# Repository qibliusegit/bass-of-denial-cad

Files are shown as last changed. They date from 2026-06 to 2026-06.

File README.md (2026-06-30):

# bass-of-denial-cad
These are the hardware-related files for the bass I'm creating for Hack Club's Stardance! As someone that loves music, I thought building a bass would be really cool, and since I also like anime, I wanted it to look like Ryo Yamada's Fender Precision from Bocchi the Rock. But because that was somehow still too boring to me, I decided to also make it so the bass can react to overplayed guitar songs, the main inspiration being the 'No stairway! Denied!' scene in Wayne's World, which you can watch by clicking here:

Watch the video (https://www.youtube.com/embed/UCh6guovbt0)

There's loads of songs that are so overplayed on guitar that hearing them annoys people, Stairway to Heaven and Smoke on the Water to name a few. So to stop guitarists from pestering an entire room full of people (or to make them practice the music they need to actually learn at a gig session), this bass uses a Raspberry Pi Zero 2 W along with a screen to stop them in their tracks. Ryo Yamada would be proud, I hope.

oke-yamada-ryo

This repo contains screenshots, STL files, and STEP files for the bass, which was fully CADed in Onshape. It also contains the wiring diagram, which I found on StewMac (the manufacturers of the pickups I'm ordering)'s website, as well as my bill of materials.

The software files for this will be uploaded in a seperate repo as I create them, since I'm currently in the process of coding the sound recogniztion software. I will link the repo here once it exists.


Full CAD of the bass


The green section represents where the riff recognition module would go. There's no fancy wiring or anything here, just a Raspberry Pi Zero 2 W hooked up to a small screen.

The purple section represents the wiring for the pickups and output jack for the bass. The specific wiring diagram can be seen here:



In this diagram, the pickups (which are on the left) would go into the holes in the middle of the guitar. The two potentiometers and the output jack would be placed near the bottom left edge (from the perspective shown in the CAD).

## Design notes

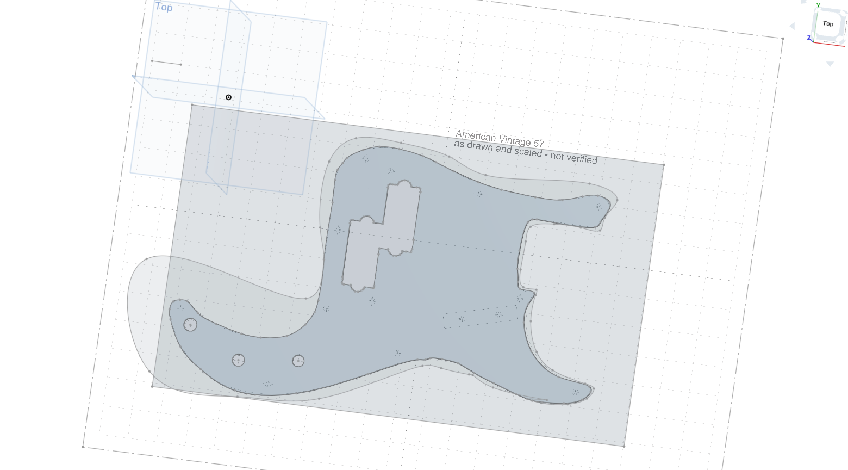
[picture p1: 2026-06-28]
bass pick guard.png

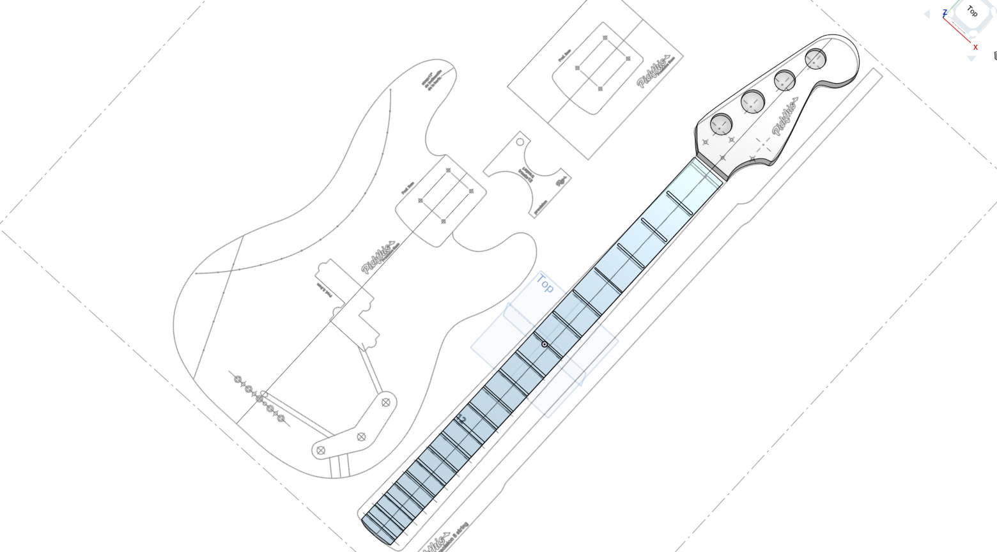
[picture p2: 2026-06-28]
bass neck and headstock.png

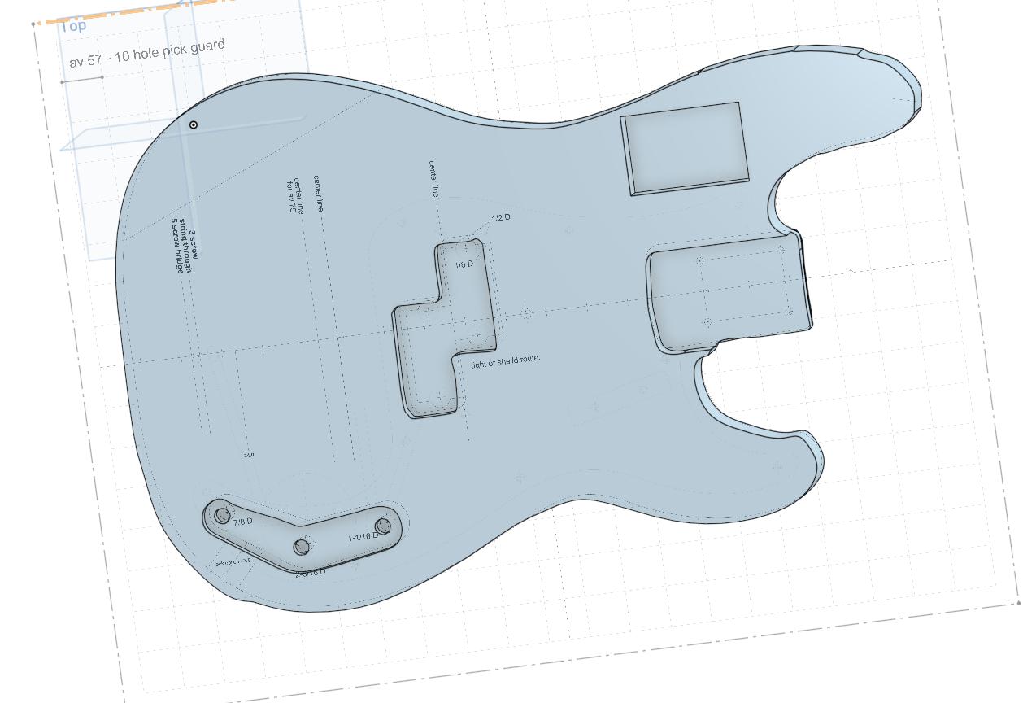
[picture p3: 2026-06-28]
bass body.png

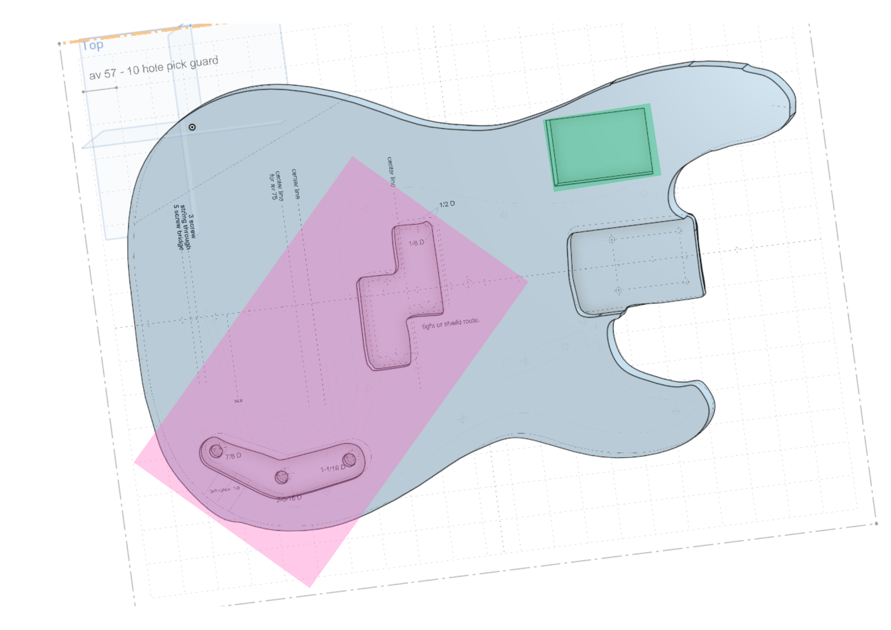
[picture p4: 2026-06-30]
bass body labelled.png

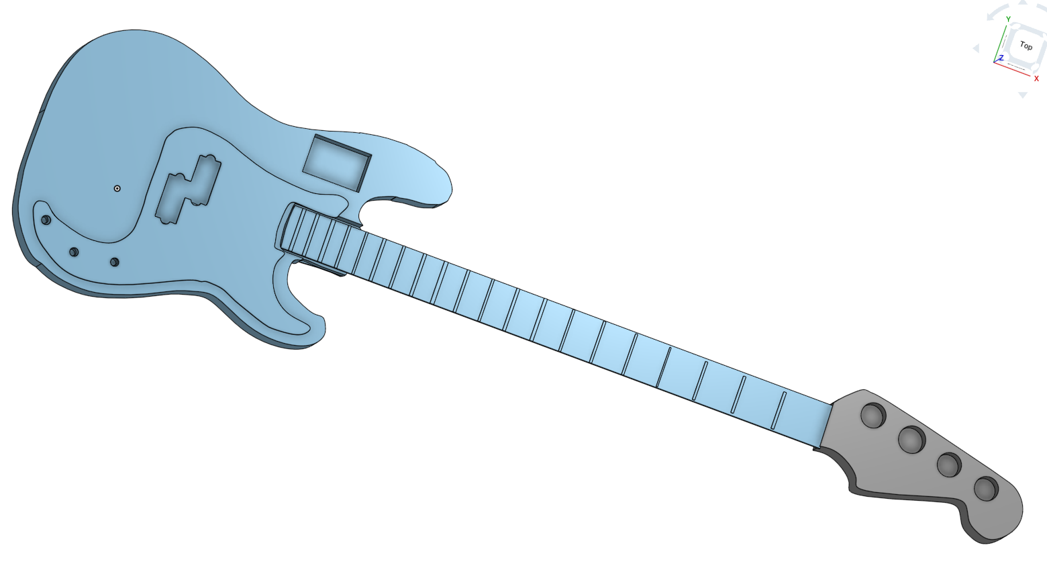
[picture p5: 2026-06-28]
bass full.png

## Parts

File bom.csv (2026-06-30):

Part Name | Part Description | Part Quantity | Total Part Price | Part Link
GOTOH VK1-19 Domed Guitar Knob for 6mm diameter pots | Knobs for volume and tone potentiometers | 2 | $9.98 | https://www.philadelphialuthiertools.com/knobs/volume-and-tone-control-knobs/gotoh-vk1-19-domed-guitar-knob-for-6mm-diameter-pots/
CTS Control Pots, Split shaft, 250K | Potentiometers for adjusting volume and tone | 2 | $16.38 | https://www.stewmac.com/electronics/components-and-parts/potentiometers/cts-control-pots/
Switchcraft 1/4" Guitar Output Jack | Jack to plug guitar into amplifier | 1 | $4.41 | https://www.philadelphialuthiertools.com/electronics/jacks/switchcraft-1-4-guitar-output-jack/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
GOTOH NBS-3 Steel Neck Plate | Plate for attaching neck to body | 1 | $9.99 | https://www.philadelphialuthiertools.com/neck-plates/gotoh-nbs-3-steel-neck-plate/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
GOTOH GB10 Bass Tuning Machines Tuners - Preconfigured Sets | Tuning machines for tuning bass strings | 1 | $46.49 | https://www.philadelphialuthiertools.com/bass-tuning-machines/gotoh-gb10-bass-tuning-machines-tuners-preconfigured-sets/
GOTOH EP-B1 Standard Size Strap Button | Buttons to attach bass strap to bass | 2 | $6.48 | https://www.philadelphialuthiertools.com/misc-hardware/gotoh-ep-b1-standard-size-strap-button/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
PIO "Blue Jacket" Capacitors for guitar .047mfd | Filters frequencies so guitar sounds right | 1 | $6.41 | https://www.philadelphialuthiertools.com/electronics/pio-blue-jacket-capacitors-for-guitar-047mfd/
StewMac Pickups for P-Bass | Senses vibration and works with amp to convert it into sound | 1 | $67.49 | https://www.stewmac.com/electronics/pickups/shop-all-our-pickups/stewmac-pickups-for-p-bass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
Hot Rod Low-profile 2-Way Truss Rod, 24" | Stabilizes neck of bass | 1 | $11.29 | https://www.stewmac.com/luthier-tools-and-supplies/materials/truss-rods/adjustable-truss-rods/hot-rod-low-profile-2-way-truss-rod/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
Jescar Stainless Steel Fretwire FW57110-S Electric Jumbo Pre-radiused, 9.5" | Shortens amount of bass string that can vibrate to make different sounds | 1 | $20.74 | https://www.philadelphialuthiertools.com/fretwire/jescar-stainless-steel-fretwire-fw57110-s-electric-jumbo-pre-radiused/
Bone Nut Pre Shaped and slotted for Fender® Precision Bass | Secures strings at correct points | 1 | $6.30 | https://www.philadelphialuthiertools.com/guitar-bass-nuts-saddles/bone-nut-pre-shaped-and-slotted-for-fender-precision-bass/
GOTOH 201B-4 4-string bass bridge | Tightens strings and holds them on body | 1 | $41.71 | https://www.philadelphialuthiertools.com/bridge-and-tailpieces/bass-bridges-and-tailpeices/gotoh-201b-4-4-string-bass-bridge/
Pickup Foam Height Springs - Precision Bass - 2 1/2" x 3/4" x 5/8" - 2 pack | Allows for adjustment of height of pickups | 1 | $2.61 | https://www.philadelphialuthiertools.com/mounting-rings/pickup-foam-height-springs-precision-bass-2-1-2-x-3-4-x-5-8-2-pack/
Raspberry Pi Zero 2 W | SBC for running program to detect sound | 1 | $17.25 | https://www.pishop.us/product/raspberry-pi-zero-2-w/?searchid=0&search_query=raspberry+pi+zero
2.8inch Capacitive Touch Display RP2350 Development Board | Screen for displaying video when specific sounds are detected | 1 | $28.95 | https://www.pishop.us/product/2-8inch-capacitive-touch-display-rp2350-development-board-240-320-ips-panel-5-point-touch-spi-accelerometer-and-gyroscope-sensor/
BNTECHGO 22 Gauge Silicone Wire red and Black | Wire for hooking up electronics | 1 | $7.48 | https://www.amazon.com/BNTECHGO-Silicone-Flexible-Strands-Stranded/dp/B01MFEV8SG?th=1
Wood | Repurposed hardwood for body, neck, and fretboard, self-sourced | 1 | $0 | N/A
Ernie Ball Regular Slinky Nickel Wound Bass Guitar Strings, 50-105 Gauge | Strings to make the bass playable | 1 | $20.42 | https://www.amazon.com/Ernie-Ball-Regular-Slinky-Nickel/dp/B000MFL7UU
Shipping + Fees from StewMac | So I can get the parts from StewMac | 1 | $22.96
Wood Glue | To make sure everything stays in one piece | 2 | $19.16 | https://www.amazon.com/Titebond-Ultimate-Wood-16-Ounces-1414/dp/B0002YQ3KA
Shipping + Fees from Philidelphia Luthier | So I can get the parts from Philidelphia Luthier | 1 | $0
 |  |  |  | Total Cost: | $366.50
 |  |  |  | (The other $10 is for leeway in cases taxes or shipping changes at all)

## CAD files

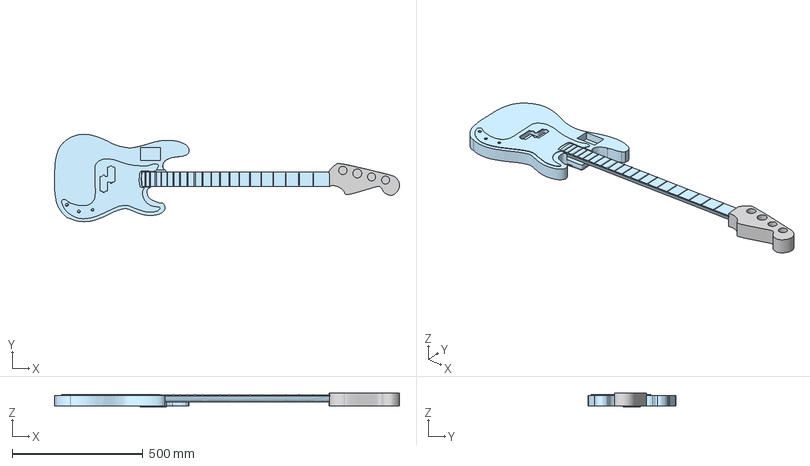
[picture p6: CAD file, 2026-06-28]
bass full.step
1317.8 x 334.3 x 54.7 mm
neck
headstock

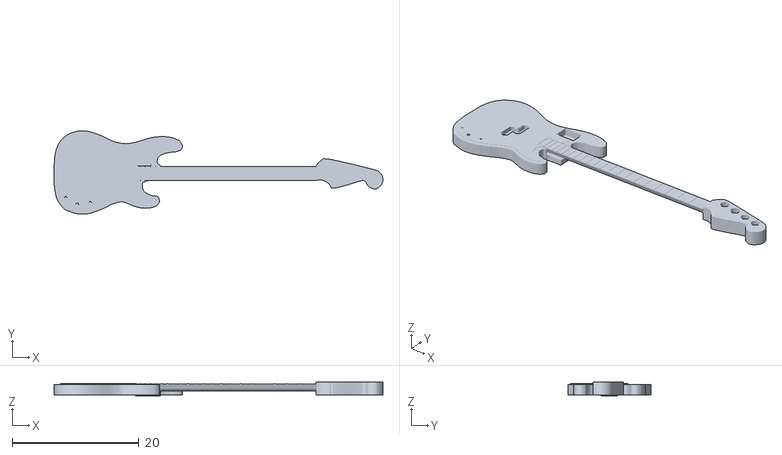
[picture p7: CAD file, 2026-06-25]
full guitar.stl
51.9 x 13.2 x 2.15

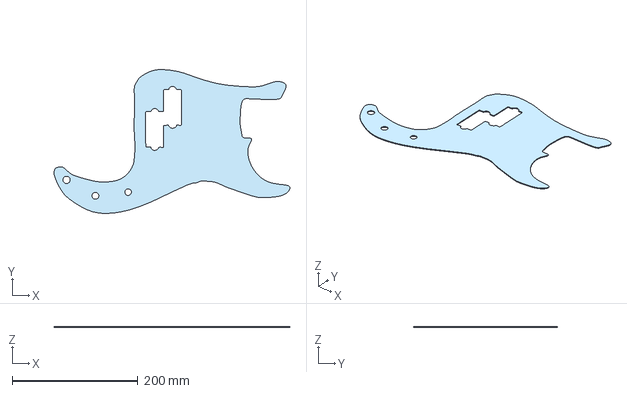
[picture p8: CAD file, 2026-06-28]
pickguard.step
375.7 x 229.0 x 1.27 mm

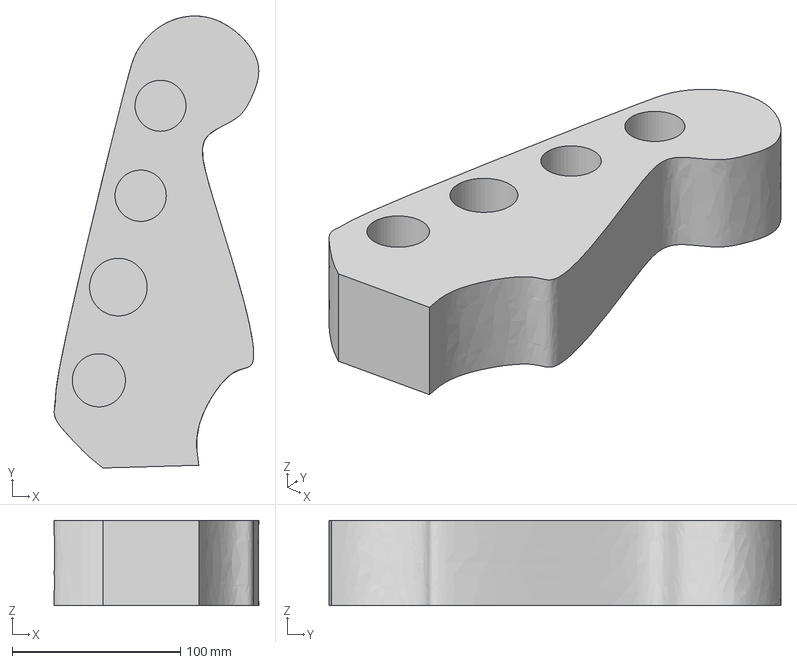
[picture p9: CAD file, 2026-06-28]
headstock.step
121.6 x 268.6 x 50.8 mm

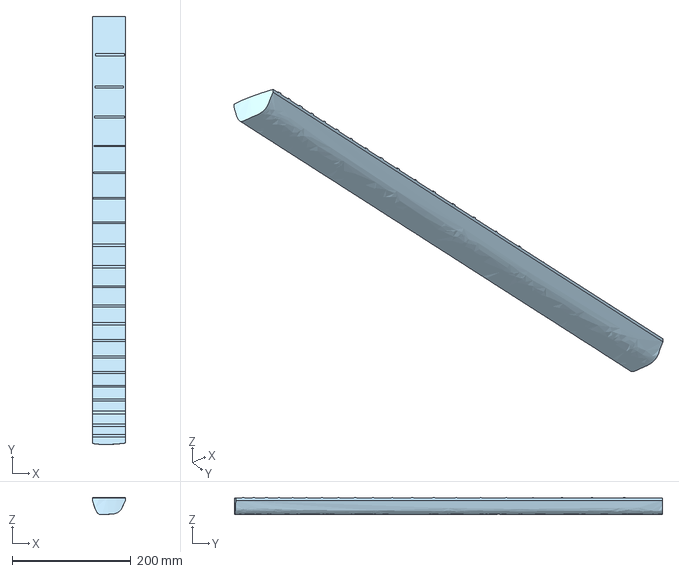
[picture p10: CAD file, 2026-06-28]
neck.step
55.8 x 720.1 x 29.2 mm

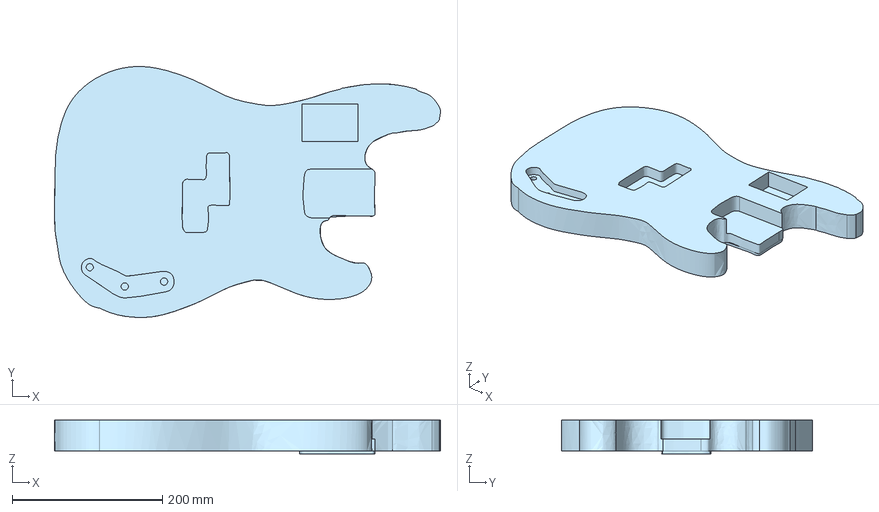
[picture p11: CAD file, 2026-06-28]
body.step
514.2 x 334.2 x 45.1 mm

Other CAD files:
body.stl
headstock.stl
neck.stl
pick guard.stl

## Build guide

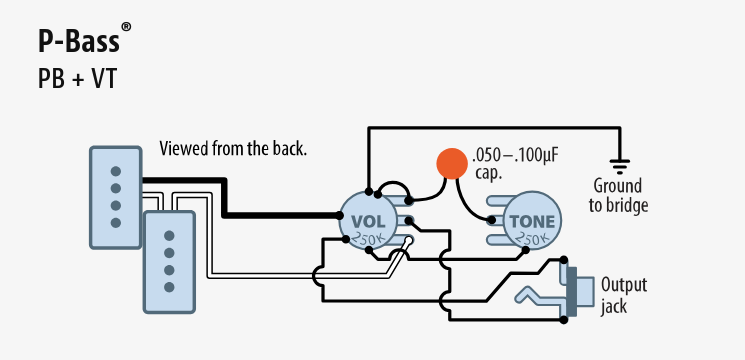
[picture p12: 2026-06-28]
wiring diagram.png

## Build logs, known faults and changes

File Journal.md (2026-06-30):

---
title: "Ra's bass of denial"\
author: "Dhruv Ravinuthala"\
description: "Bass that stops pesky guitarists from playing overused songs"\
created_at: "2026-06-23"\
(all timestamps are from my Lapse timelapses, times are in Central Time)\

---
# **June 23rd**

3:21 AM - Made a draft of the body. This didn't involve anything fancy and was just me freeCADing with the plan I found online as a reference image. 

The reference image was able to help a bit with making it, but overall it's shown that this isn't going to look good unless I find a way to upload the image onto OnShape and use it to draw out the bass.



_in all honesty, calling this body not good would probably be a little bit TOO nice to it :(. it has a great personality tho!_

Time spent working: 16 minutes
Lapse link: https://lapse.hackclub.com/timelapse/n1zyYGAF6e8Q

10:50 PM - Made a proper body for the guitar, actually using the plan as an outline to properly stencil everything out. 

It unsurprisingly looks a lot better than the first body I made. The only real struggle I had was figuring out how to upload the image in the first place. I don't enjoy admitting that it took me a solid 10 minutes to realize that I needed to be in a sketch first so I could upload it 😭. Once I got that done and figured out the grid scale was 1 inch (thankfully Fender has dimensions on their website). 



_the difference between the first body and this one is "you vs the guy she tells you not to worry about"_

Time spent working: 1 hour
Lapse link: https://lapse.hackclub.com/timelapse/l_hfG1_XWVQF

---
# **June 24th**

12:45 AM - Made a draft of the pickguard using the plan. It came out a little wobbly with the cutouts for the pickups, and will need some editing later. 

This showed me that as nice as splines are, they can't do everything. I need to rely a lot more on just using straight lines and then using splines to connect them together. Everything else came out pretty well though, so I'm happy with it. The outer area doesn't need to be perfect but the holes for the pickups (in the middle) and the tone/volume knobs (bottom) left need to be as accurate as possible, so I have to be careful with them.

\
(sorry that the image isn't amazing, i didn't take a screenshot when I made it so I just pulled from the timelapse)

_vErY wObBlY_

Time spent working: 15 minutes
Lapse link: https://lapse.hackclub.com/timelapse/mZLxeXS8IVZw

1:08 AM - Started work on the neck, though there wasn't much progress due to my WiFi drivers failing on me randomly. There's not much else to report sadly.

Time spent working: 2 minutes
Lapse link: https://lapse.hackclub.com/timelapse/nm29G0AQ-VNF

2:34 AM - Actually got work done on the neck, pretty much everything that was necessary except for radiusing it. 

Since I knew how to upload images this time I just needed to find a plan of it online. Dimensions were pretty easily found thanks to the fact that the Fender Precision is the mother of all bass guitars, so I knew the neck was 34 inches long. I tried radiusing with the fillet tool, though I don't really know how it works so it didn't go very well. I need to mess with other tools in OnShape so I can figure out what will work.

\
(sorry that the image isn't amazing, i didn't take a screenshot when I made it so I just pulled from the timelapse)

_i don't really know what flavor text would be interesting to put here. so, uhhh, how's your day going?_

Time spent working: 20 minutes
Lapse link: https://lapse.hackclub.com/timelapse/q9EjQVwE_udU

10:08 AM - Radiused the neck and cleaned up other files, mainly working on making the pickup cutouts on the pick guard less wobbly in random spots and more consistent. 

So it turns out that all I really needed to radius the neck was the wonderful extrude tool (I feel like every day I find out another reason that 95% of CADing {for me at least} is just using the extrude tool). I then made the headstock, which was much simpler than anything else I've made so far, thanks to the fact that I only needed to put 4 holes there for each tuning machine. As for the pickguard, I learned my lesson and worked more with straight lines to keep everything consistent, using splines only when there were unavoidable curves. This resulted in a pickguard that doesn't look incredibly wobbly.



_woah it's a neck and headstock_



_much **steadier.**_

Time spent working: 30 minutes
Lapse link: https://lapse.hackclub.com/timelapse/mW1IGIKW8RZF

10:19 AM - Finished up cleaning up the individual parts and assembled them together, added a hole where the screen and Raspberry Pi with the sound recognition would fit.

There wasn't really anything fancy done here, just a couple touch-ups to make sure that shapes were as accurate as possible. As for the screen and Pi, I used the dimensions of a 2.8in touch screen I found and then increased them slightly, as well as making a deeper cavity, so there was room for the Pi and a battery of some sort. I then just used OnShape's wonderful assembly view to snap everything into place. Now, instead of virtual pieces of a bass, I have an entire virtual bass!



_now i am become ryo yamada, greatest bass player (hopefully)_

Time spent working: 7 minutes
Lapse link: https://lapse.hackclub.com/timelapse/ckrJw6c99PDP

---

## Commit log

2026-06-25 Added guitar parts
    [body.stl, full guitar.stl, headstock.stl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]
2026-06-28 Added STEP files and wiring diagram.
    [bass full.step, body.step, headstock.step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]
2026-06-28 added bill of materials
    [bom.csv]
2026-06-28 added updated bill of materials, since strings are kinda important
    [bill of materials.csv]
2026-06-28 Rename bill of materials.csv to bom.csv
    [bom.csv]
